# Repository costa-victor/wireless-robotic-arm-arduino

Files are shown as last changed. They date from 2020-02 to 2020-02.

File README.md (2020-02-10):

## Robotnik -> Equipe de robótica da UTFPR - Pato Branco
## Descrição do projeto:
Em resumo trata-se de um Braço robótico de 4 Eixos impresso em 3D controlado remotamente por um Controle de PS2 que consiste basicamente de 2 Módulos, conforme a imagem abaixo:

description

Os códigos comentados e todo o material necessário para criação e/ou continuação desde projeto estão contidos nesse repositório na pasta **Code**.

A seguir você encontrará a descrição do funcionamento, referências, demonstração e dicas para aprimorar o projeto atual.

### Module 1:
 A função do **Arduino** neste módulo é de receber e interpretar os dados ao pressionar/mover algum de seus botões/analógico do **Controle de PS2** e armazenar os dados em uma struct contendo o estado de cada botão e enviar para o **Module 2** via **Wireless RF** com o **NRF24L01**.
 
 **Hardware:**
 - 01x NRF24L01
 - 01x Arduino Uno
 - 01x Controle PS2 (qualquer)
 
 O **Controle PS2** utilizado foi um controle sem fio, contudo, as conexões permanecem as mesmas da imagem abaixo.
 
 
 
 Para mais informações sobre o **Module 1**, recomendo os materiais:
 * [Como funciona os pinos do Controle PS2]( http://microcontrolado.com/controle-playstation-no-pic-2/)
 * [Como funciona o NRF24L01]( https://lastminuteengineers.com/nrf24l01-arduino-wireless-communication/)
 * [Documentação da Lib para o NRF24L01]( https://maniacbug.github.io/RF24/classRF24.html#aeb9920e7a95699748b003c4a839b0814)

### Module 2:
 A função do **Arduino** neste módulo é de receber os dados enviados do **Module 1** e com isso gerar instruções para o jogador através do **Display LCD** e ao mesmo tempo enviar um sinal PWM aos **Servo-motores** para assim mover o **Braço Robótico de 4 eixos impresso em 3D**  como desejar, dentro dos movimentos que os **Servo-motores** permitem e são eles:
 
 - Rotaçao da **Base** em até 180º
 - Erguer/Abaixar o **Braço**
 - Esticar/Contrair o **Antebraço**
 - Fechar/Abrir **Garra** 

Todos os movimentos acima são exibidos no **Display LCD**.
 
 **Hardware:**
 - 01x NRF24L01
 - 01x Arduino Uno
 - 02x Servo-Motor SG90
 - 02x Servo-Motor MG995
 - 01x Fonte ATX (simples)

 Neste projeto foi necessário utilizar um **Servo-Motor MG995** para a movimentação do **Braço** e outro para movimentação do **Antebraço** por conta da necessidade de maior torque dos motores para funcionar, enquanto para a **Garra** e a **Base** a utilização do **Servo-Motor SG90** foi suficiente.
 
 Para alimentação do **Module 2**  foi utilizado uma **Fonte ATX**, pois é permitido executar os 4 movimentos simultaneamente e a utilização de um regulador linear como o **LM7805** não é suficiente para a alimentação de todo o **Module 2**, pois durante a execução de movimentos combinados a corrente necessária foi superior à **2,5 A** e portanto caso desejar uma solução mais elegante que a utilização de uma **Fonte ATX**, sugiro utilizar um **Conversor DC/DC (Step Down) LM2596** ou similar.
 
O projeto original, utilizado como base para montagem e adaptação em um braço robótico de 4 eixos que pode ser encontrado abaixo em **Montagem do Braço**, deste vários arquivos **STL** que compoêm o braço precisaram ser modificadas, pois o projeto original conta com uma **Bomba de Sucção**, que foi substituída por uma **Garra** e utilizada como referência o material abaixo **Garra adaptada**.

Todas as alterações nos arquivos **STL** foram realizadas utilizando o software **Autocad 2012 Student Version** e estão contidos neste repositório na pasta **3D Files**.

Todas as substituições de peças do projeto original podem ser comparadas acessando o arquivo **orçamento**.

 Para mais informações sobre o **Module 2**, recomendo os materiais:
 * [Documentação Lib Display LCD]( https://www.arduino.cc/en/Reference/LiquidCrystal)
 * [Montagem do Braço](https://www.youtube.com/watch?v=dlAjBVg1W2E&t=)
 * [Garra adaptada]( http://www.eezyrobots.it/eba_mk2.html#)

### Demonstração/Resultado:
Teste realizado antes de integrar com o montagem do braço impresso.

 demonstration1

Finalizado a montagem.

 final
 
 E deixando o melhor para o final, tem também um [vídeo](https://www.youtube.com/watch?v=mlnH6SM9yyg) demonstrando o funcionamento após o termino da montagem.

### Integrantes: Victor Alberti Costa e Murilo Santos Alves

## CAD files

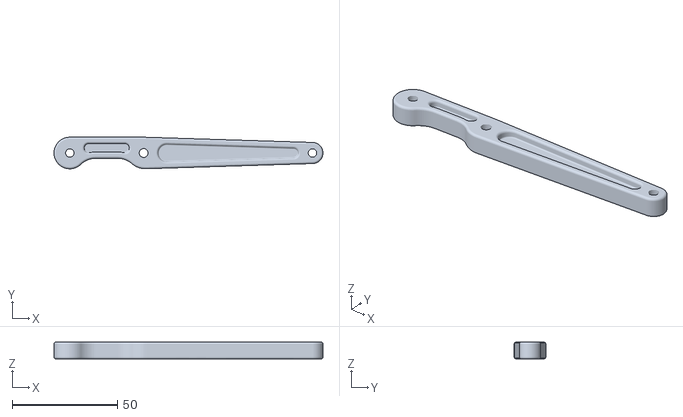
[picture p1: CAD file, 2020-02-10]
3D Files/Garra adaptada/EBA_01.00.005_horizontal_arm.STL
127.5 x 15.0 x 8.00

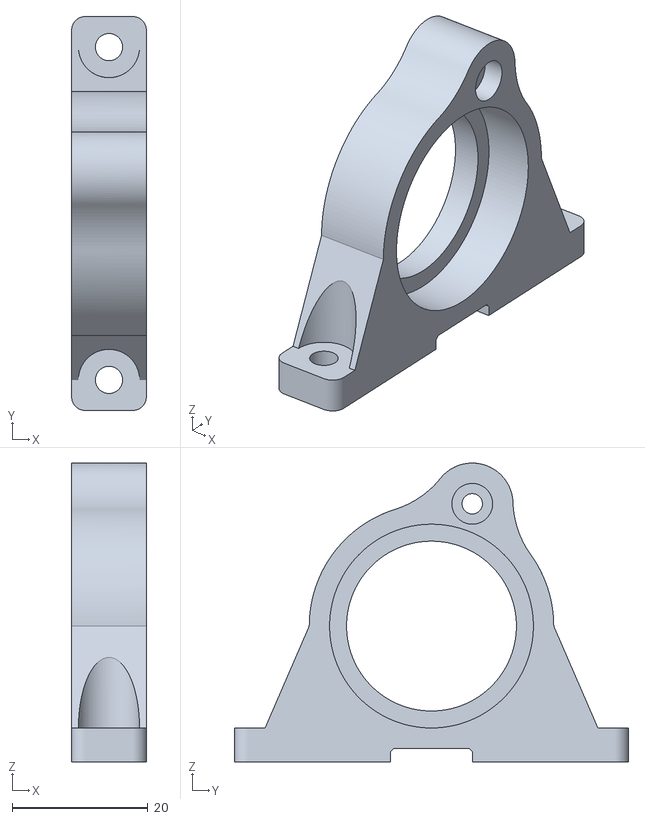
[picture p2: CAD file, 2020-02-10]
3D Files/stl/PART_9.stl
11.0 x 58.0 x 44.0

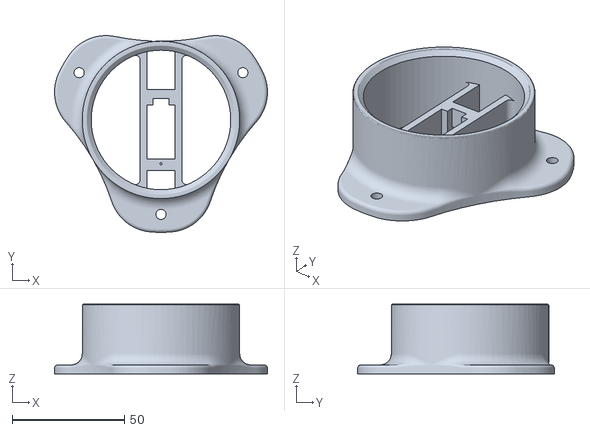
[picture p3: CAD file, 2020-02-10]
3D Files/Garra adaptada/EBA_01.00.010_basement.STL
94.7 x 87.5 x 31.0

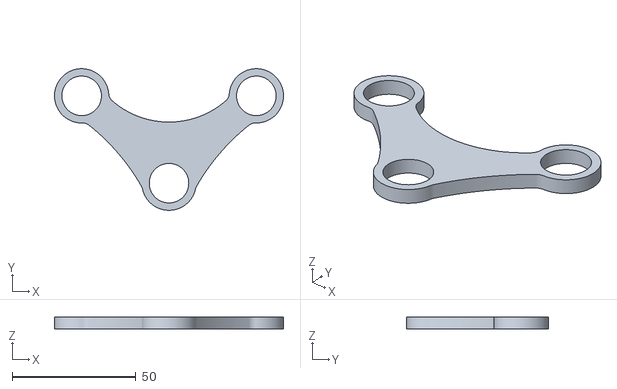
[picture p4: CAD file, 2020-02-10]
3D Files/stl/PART_17.stl
92.7 x 57.3 x 5.00

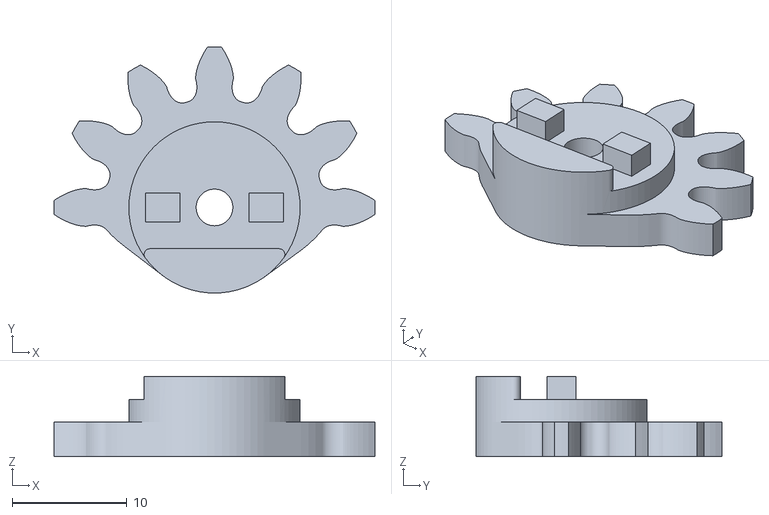
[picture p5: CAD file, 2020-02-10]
3D Files/Garra adaptada/EBA_01.00.016_R01_driven_gear.STL
28.0 x 21.5 x 7.00

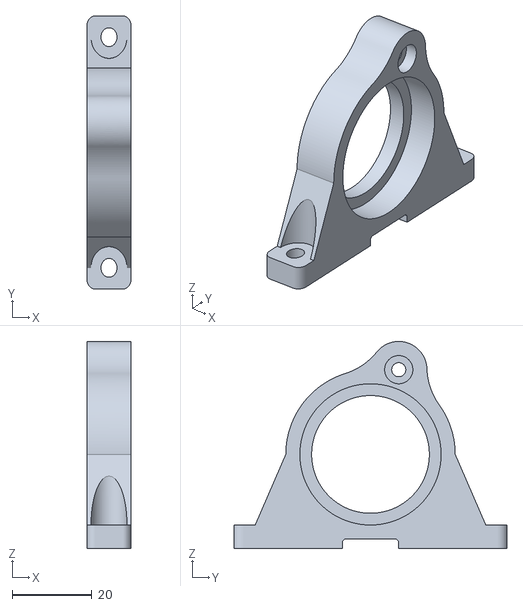
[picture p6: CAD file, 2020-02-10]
3D Files/stl/PART_9 - modificado.stl
11.0 x 68.4 x 51.9

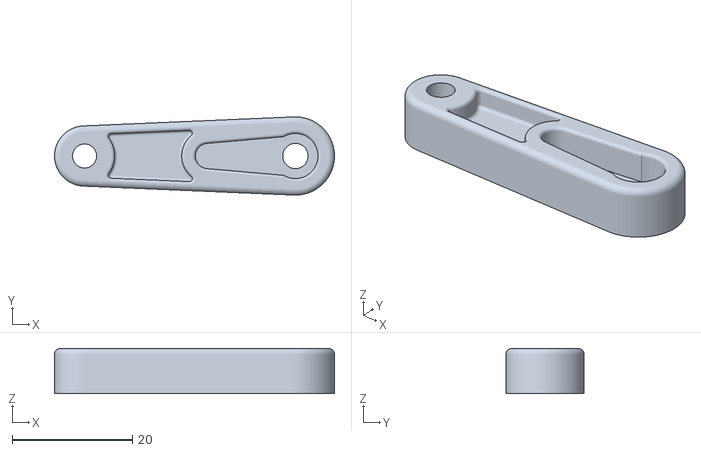
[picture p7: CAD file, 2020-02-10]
3D Files/Garra adaptada/EBA_01.00.002_vertical_drive_arm.STL
46.5 x 13.0 x 7.50

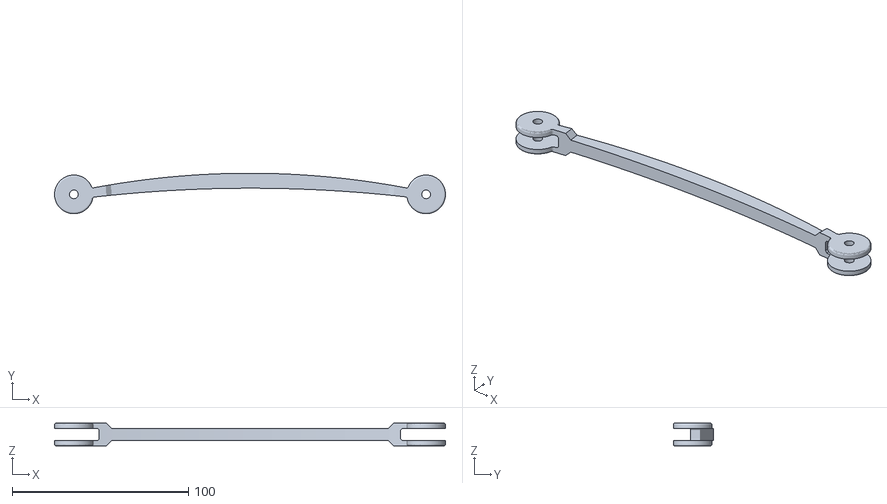
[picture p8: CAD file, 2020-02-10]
3D Files/stl/2x_PART_22.stl
222.0 x 23.0 x 13.0

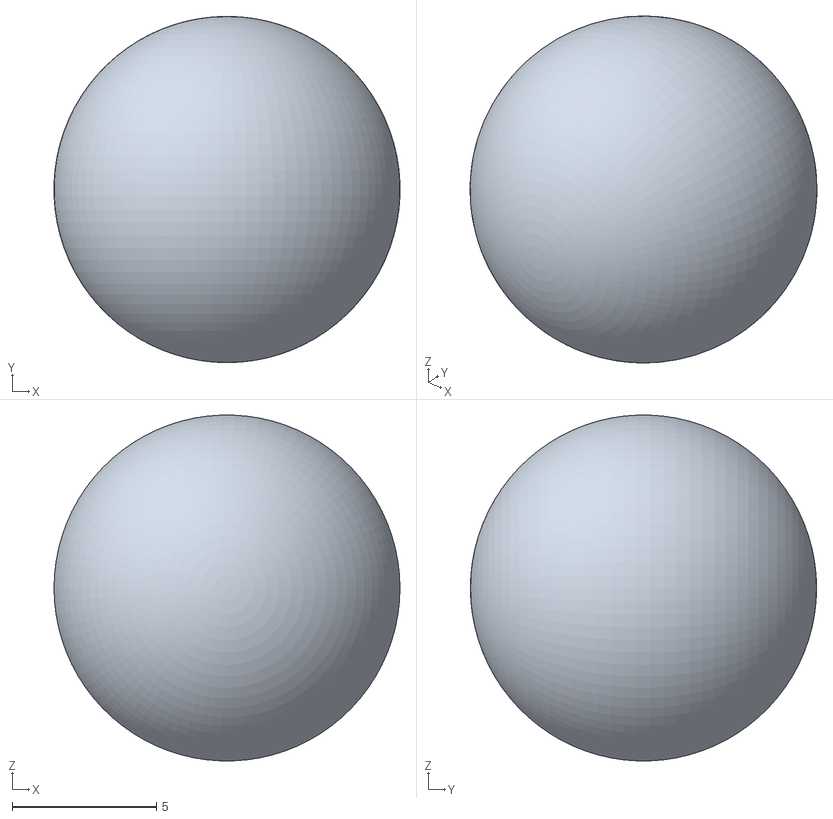
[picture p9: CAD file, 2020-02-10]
3D Files/Garra adaptada/EBA_01.00.019_ball.STL
12.0 x 12.0 x 12.0

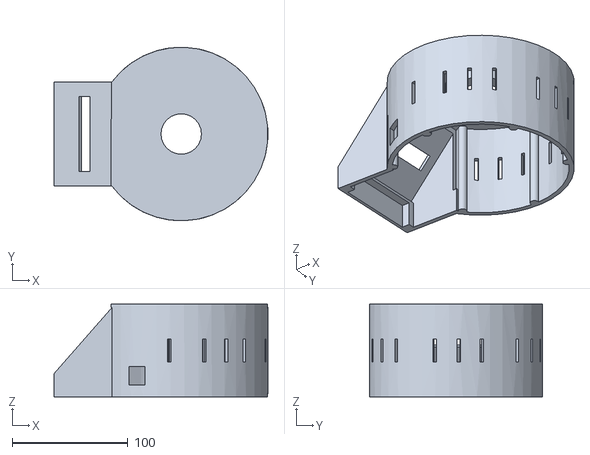
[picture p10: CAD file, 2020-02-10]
3D Files/stl/parte 1 - autocad - teste2.stl
185.0 x 149.9 x 80.0

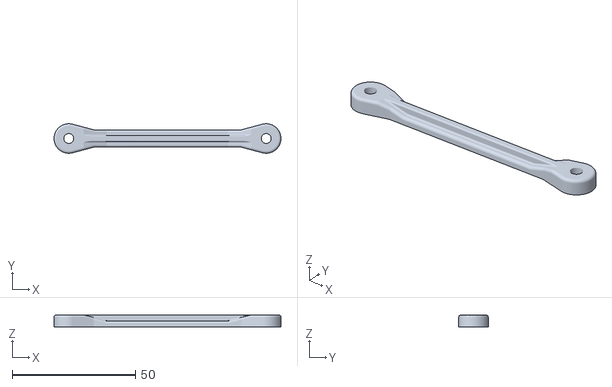
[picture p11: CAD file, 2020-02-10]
3D Files/Garra adaptada/EBA_01.00.003_link.STL
92.0 x 12.0 x 5.00

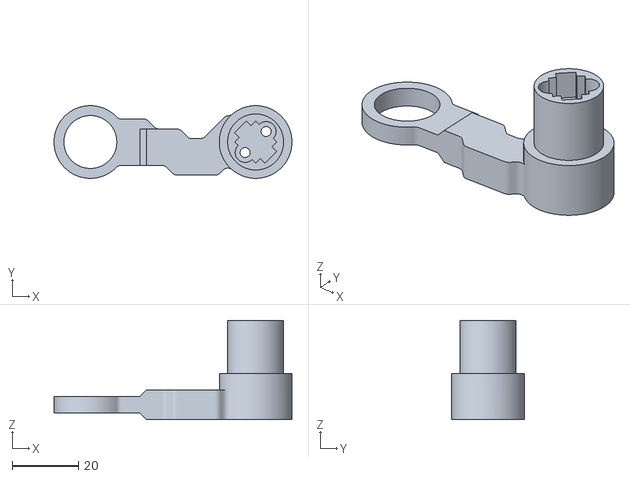
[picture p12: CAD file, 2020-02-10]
3D Files/stl/PART_10.stl
72.0 x 22.0 x 30.0

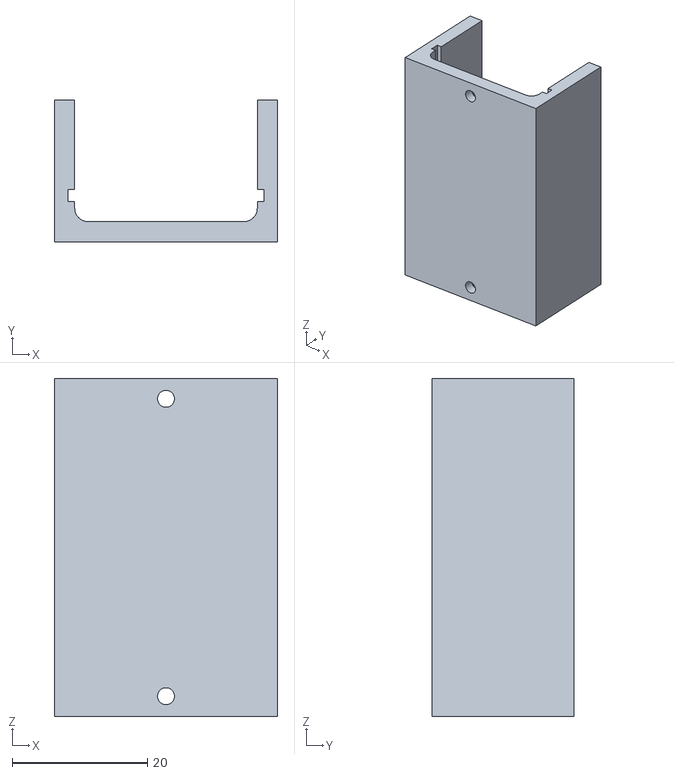
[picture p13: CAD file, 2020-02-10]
3D Files/Garra adaptada/EBA_01.00.018_maestro_holder.STL
33.0 x 21.0 x 50.0

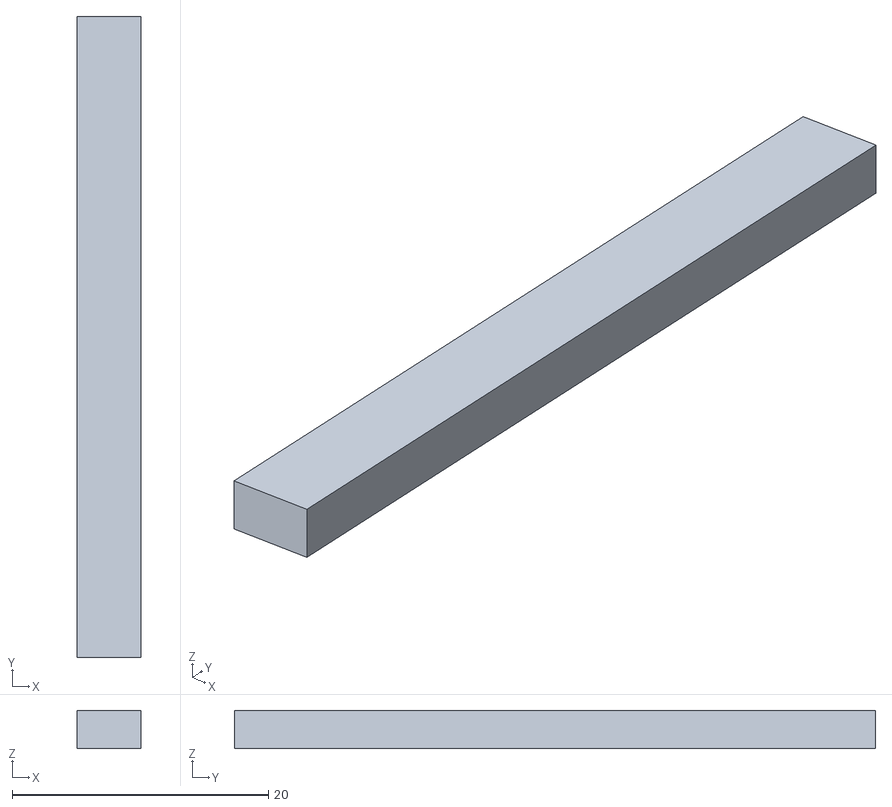
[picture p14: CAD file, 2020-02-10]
3D Files/stl/apoioAuxiliar.stl
5.00 x 50.0 x 3.00

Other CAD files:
3D Files/dwg/parte 23 - sketchup.dwg
3D Files/dwg/Peça 16 - autocad.dwg
3D Files/dwg/parte 9 - autocad.dwg
3D Files/Garra adaptada/EBA_01.00.013_R01_right_finger.STL
3D Files/Garra adaptada/EBA_01.00.001.STL
3D Files/Garra adaptada/EBA_01.00.004_forward_drive_arm.STL
3D Files/Garra adaptada/EBA_01.00.006_triangular_link.STL
3D Files/Garra adaptada/EBA_01.00.009_servo_plate.STL
3D Files/Garra adaptada/EBA_01.00.011_round_plate.STL
3D Files/Garra adaptada/EBA_01.00.012_R01_claw_support.STL
3D Files/Garra adaptada/EBA_01.00.014_R01_left_finger.STL
3D Files/Garra adaptada/EBA_01.00.015_drive_gear.STL
3D Files/Garra adaptada/EBA_01.00.017_R01_ramp.STL
3D Files/dwg/Peça 16 - autocad - pt1.dwg
3D Files/dwg/Peça 16 - autocad - pt2.dwg
3D Files/dwg/Peça 16 - autocad - pt3.dwg
3D Files/dwg/apoioAuxiliar.dwg
3D Files/dwg/apoioAuxiliarDaPt4.dwg
3D Files/dwg/apoioAuxiliarDoMotor.dwg
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

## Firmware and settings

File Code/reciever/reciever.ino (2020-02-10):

/* Projeto de oficina de integração --- Curso Engenharia de computação --- 7º Período
 * Autor: Victor Alberti Costa, Murilo Alves
 * Email: victorengcomp15@gmail.com
 * 
 * MÓDULO RECIEVER
 * 
 * Código referente ao módulo receptor de sinal proveniente do módulo RF do transmissor
 * e movimentação de 4 servomotores e um display LCD.
 * 
 * INSTRUÇÕES DE USO:
 *   Aberte START para começar
 *   Informe-se pelo display e divirta-se :)
 * 
 *    Movimentação BASE:
 *      ->  Seta para esquerda gera movimento no sentido Anti-horário
 *      ->  Seta para direita gera movimento no sentido Horário
 *      
 *    Movimentação BRAÇO:
 *      ->  Seta para cima gera movimento para frente
 *      ->  Seta para baixo gera movimento para trás
 *      
 *    Movimentação ANTEBRAÇO:
 *      ->  Analógico Direito pressionado para cima gera movimento para frente
 *      ->  Analógico Direito pressionado para baixo gera movimento para trás
 *      
 *    Movimentação GARRA:
 *      ->  Segurar R1 fecha a garra
 *      ->  Soltar R1 abre a garra
 */

#include <SPI.h>  
#include <RF24.h>
#include <Servo.h>
#include <LiquidCrystal.h>

LiquidCrystal lcd(7, 8, 5, 4, 3, 2); // lcd(rs, en, d4, d5, d6, d7) 
Servo base, braco, garra, antebraco;
RF24 myRadio (9, 10); // CE, CS

// variaveis utilizadas para controle do ang. dos servomotores
int posBase = 90;
int posBraco = 90;
int posAntebraco = 90;

// Estrutura dos dados que estão sendo enviados do transmissor - idem no transmissor
struct package
{
  int id=1;
  int LY;
  int LX;  
  int RY;
  int RX;
  int up;
  int down;
  int left;
  int right;
  int L1;
  int L2;
  int R1;
  int R2; 
  int start;  
  int x;
  int square;   // Consegue receber até aqui
  int triangle;
  int circle;
};

typedef struct package Package;
Package data;

// Definição do pipe de comunição do módulo RF
byte addresses[][6] = {"0"}; 

byte smiley[8] = {
  0b00000,
  0b00000,
  0b01010,
  0b00000,
  0b00000,
  0b10001,
  0b01110,
  0b00000
};


void setup() {
  // Incialização do display LCD
  lcd.begin(16, 2);
  lcd.createChar(1, smiley);
  lcd.clear();  
  
  // Mensagem inicial
  lcd.print("Pressione START");
  lcd.setCursor(0, 1);
  lcd.print("para comecar");

  // Inicialização dos servomotores
  base.attach(A5);
  braco.attach(A4);
  garra.attach(A0);
  antebraco.attach(A3);

  // Inicialização do monitor serial
  Serial.begin(57600);

  // Movimentação dos motores para testes
  delay(1000);
  base.write(90);
  braco.write(90);
  antebraco.write(90);
  garra.write(0);

  // Configuração do módulo RF
  // Documentação da biblioteca: https://maniacbug.github.io/RF24/classRF24.html#aeb9920e7a95699748b003c4a839b0814
  myRadio.begin(); 
  myRadio.setChannel(115);  // Canais de 0 - 127
  myRadio.setPALevel(RF24_PA_MAX);  // Power Level Amplifier - Máximo
  myRadio.openReadingPipe(1, addresses[0]);  // Numero identificador do pipe e seu endereço
  myRadio.setDataRate( RF24_250KBPS );  // Taxa de transmissão

  // Começa a ouvir o pipe
  myRadio.startListening(); 

  // Enquanto não ler o dado corresponde ao start, continua ouvindo
  do{
     if(myRadio.available()){
      while (myRadio.available()){
         myRadio.read( &data, sizeof(data) );
      }
    }  
  }while(!data.start);

  // Motivacional
  lcd.clear();
  lcd.setCursor(2, 0);
  lcd.print("Divirta-se ");
  lcd.write((byte)1);
}


void loop() {
  // Sempre que recebe um dado, lê e armazena na struct data
  if ( myRadio.available()) 
  {    
    while (myRadio.available())
    {
      myRadio.read( &data, sizeof(data) );
    }

  // Inicio da verificação dos dados para tomar ações

  // Caso seja pressionado botões que contradizem o movimento, informa o usuário
  if((data.left == 1 && data.right == 1) || (data.up == 1 && data.down == 1)){
        lcd.clear();      
        lcd.setCursor(4, 0);
        lcd.print("Movimento");      
        lcd.setCursor(5, 1);
        lcd.print("Invalido");
    }
    else{
          // Lógica para a base
          // Conectado: Pin A5

          // Se pressionado Seta Esquerda
          if(data.left == 1){
            if(data.right || data.up || data.down){
              lcd.clear();      
              lcd.setCursor(4, 0);
              lcd.print("Movimento");      
              lcd.setCursor(5, 1);
              lcd.print("Diagonal");               
            }
            else{
              lcd.clear();      
              lcd.setCursor(0, 0);
              lcd.print("Movendo BASE...");      
              lcd.setCursor(2, 1);
              lcd.print("Horario");
            }            
            // Para dar movimento mais fluido e restringir o movimento para não forçar a estrutura
            if(posBase >= 10){  
              posBase = posBase - 5; 
              base.write(posBase);
            }
            else{
              lcd.clear();      
              lcd.setCursor(0, 0);
              lcd.print("Cuidado");      
              lcd.setCursor(2, 1);
              lcd.print("Limite !!");              
            }
          }
          
          // Se pressionado Seta Direita
          else if(data.right == 1){ 
            if(data.left || data.up || data.down){
              lcd.clear();      
              lcd.setCursor(4, 0);
              lcd.print("Movimento");      
              lcd.setCursor(5, 1);
              lcd.print("Diagonal");               
            }
            else{             
              lcd.clear();      
              lcd.setCursor(0, 0);
              lcd.print("Movendo BASE...");      
              lcd.setCursor(2, 1);
              lcd.print("Anti-horario");
            }                    
            if(posBase <= 160){
              posBase = posBase + 5;
              base.write(posBase);
            }
            else{
              lcd.clear();      
              lcd.setCursor(0, 0);
              lcd.print("Cuidado");      
              lcd.setCursor(2, 1);
              lcd.print("Limite !!");              
            }
          }
      
          // Lógica para o braço
          // Conectado: Pin A4
          
          // Se pressionado a Seta Para cima
          if(data.up == 1){
            if(data.right || data.left || data.down){
              lcd.clear();      
              lcd.setCursor(4, 0);
              lcd.print("Movimento");      
              lcd.setCursor(5, 1);
              lcd.print("Diagonal");               
            }
            else{             
              lcd.clear();      
              lcd.setCursor(0, 0);
              lcd.print("Movendo BRACO...");      
              lcd.setCursor(2, 1);
              lcd.print("Frente");
            }
            
            // Para dar movimento mais fluido e restringir o movimento para não forçar a estrutura
            if(posBraco >= 10){
              posBraco = posBraco - 5;
              braco.write(posBraco);    
            }
            else{
              lcd.clear();      
              lcd.setCursor(0, 0);
              lcd.print("Cuidado");      
              lcd.setCursor(2, 1);
              lcd.print("Limite !!");              
            }
          }

          // Se pressionado a Seta Para Baixo
          else if(data.down){
            if(data.right || data.up || data.left){
              lcd.clear();      
              lcd.setCursor(4, 0);
              lcd.print("Movimento");      
              lcd.setCursor(5, 1);
              lcd.print("Diagonal");               
            }
            else{
            lcd.clear();      
            lcd.setCursor(0, 0);
            lcd.print("Movendo BRACO...");      
            lcd.setCursor(2, 1);
            lcd.print("Atras");
            }

            // Reduzindo velocidade do braço
            if(posBraco <= 170){
              posBraco = posBraco + 5;
              braco.write(posBraco);
                
            }
            else{
              lcd.clear();      
              lcd.setCursor(0, 0);
              lcd.print("Cuidado");      
              lcd.setCursor(2, 1);
              lcd.print("Limite !!");              
            }            
          }

          // Como os motores utilizados são fracos eles não conseguem manter o braço imóvel, então quando
          // nada é pressionado o motor tenta manter o braço imóvel
          else if(!data.up && !data.down){
            posBraco = 90;
            braco.write(posBraco);
          }

         
          // Lógica para o Antebraço
          // Conectado: Pin A3
          
          // Se pressionado o analógico direito   
          if(data.RY < 127){
            lcd.clear();      
            lcd.setCursor(0, 0);
            lcd.print("Mov. ANTEBRACO");      
            lcd.setCursor(2, 1);
            lcd.print("Para cima");

            // Valores do PWM ajustados empiricamente
            // Parte onde necessita de maior torque dos motores, portanto o movimento mais suave
            // não dava bons resultados
            antebraco.write(0);
          }
          else if(data.RY > 127){
            lcd.clear();      
            lcd.setCursor(0, 0);
            lcd.print("Mov. ANTEBRACO");      
            lcd.setCursor(2, 1);
            lcd.print("Para baixo");

            antebraco.write(180);
          }
          // Como os motores utilizados são fracos eles não conseguem manter o braço imóvel, então quando
          // nada é pressionado o motor tenta manter o braço imóvel
          else if(data.RY == 127){
            antebraco.write(90);
          }

      
          // Lógica para a garra  -- microservo
          // Conectado: Pin A0
          
          // Se R2 estiver pressionado
          if(data.R2){
            lcd.setCursor(0, 0);
            lcd.clear();
            lcd.print("Ativando GARRA");

            garra.write(120);
          }
          else{
            garra.write(0);      
          }

          // Se nada estiver pressionado
          if(!data.left && !data.right && !data.up & !data.down && !data.R2 && data.RY == 127)
            lcd.clear();
      }            
  }

  // Para verificação no monitor serial
  Serial.print("\nPackage Receptor: ");
  Serial.print(data.id);
  Serial.print("\n");
  Serial.println(data.LX, DEC);
  Serial.print(",");
  Serial.println(data.LY, DEC);
  Serial.print(",");
  Serial.println(data.RX, DEC);
  Serial.print(",");
  Serial.println(data.RY, DEC);
  Serial.print("X: ");
  Serial.print(data.x);
  Serial.println("");
  
  Serial.print("Square: ");
  Serial.print(data.square);
  Serial.println("");
  
  Serial.print("Triangle: ");
  Serial.print(data.triangle);
  Serial.println("");
  
  Serial.print("Circle: ");
  Serial.print(data.circle);
  Serial.println("");
  
  Serial.print("Start: ");
  Serial.print(data.start);
  Serial.println("");

  Serial.print("up: ");
  Serial.print(data.up);
  Serial.println("");

  Serial.print("down: ");
  Serial.print(data.down);
  Serial.println("");

  Serial.print("left: ");
  Serial.print(data.left);
  Serial.println("");

  Serial.print("right: ");
  Serial.print(data.right);
  Serial.println("");


  Serial.print("L1: ");
  Serial.print(data.L1);
  Serial.println("");

  Serial.print("R1: ");
  Serial.print(data.R1);
  Serial.println("");

  Serial.print("L2: ");
  Serial.print(data.L2);
  Serial.println("");

  
  Serial.print("R2: ");
  Serial.print(data.R2);
  Serial.println("");
 
  data.id = data.id + 1;

}

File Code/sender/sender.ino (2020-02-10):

#include <PS2X_lib.h>
#include <SPI.h>
#include <RF24.h>
#include <printf.h>

RF24 myRadio (9, 10); // CE, CS
PS2X ps2x; // Criação de uma instancia de controle PS2

int error = 0;
byte type = 0;
byte vibrate = 0;

byte addresses[][6] = {"0"};

struct package
{
  int id=1;
  int LY;
  int LX;  
  int RY;
  int RX;
  int up;
  int down;
  int left;
  int right;
    int L1;
  int L2;
  int R1;
  int R2;
    int start;  
  int x;
  int square;   // Envia até aqui
  int triangle;
  int circle;


};


typedef struct package Package;
Package data;

void setup() { 
  // Address: 0
  // Channel: 115
  // Data Rate: 250 Kbit
  
  // Inicialização da comunicação serial
  Serial.begin(57600);
  delay(1000);
  
  // Configuraçao do modulo RF
  myRadio.begin();  
  myRadio.setChannel(115);  // Modulo suporta 128 canais diferentes, definimos o canal do pipe que queremos usar para a comunicação
  myRadio.setPALevel(RF24_PA_MAX);    // seta o valor maximo de poder para o alcance do modulo
  myRadio.setDataRate( RF24_250KBPS ) ;   //  data rate da transmissão -- menor datarate possível pra atender melhor o longo alcance
  myRadio.openWritingPipe( addresses[0]); // abrindo o pipe para comunicaação

   // Configuração do controle PS2
   // GamePad(clock, command, attention, data, Pressures?, Rumble?)
   error = ps2x.config_gamepad(8,6,5,7, false, false);  

    // Confirmação de sucesso ou falha
   if(error == 0){
     Serial.println("Found Controller, configured successful");
     Serial.println("Try out all the buttons, X will vibrate the controller, faster as you press harder;");
     Serial.println("holding L1 or R1 will print out the analog stick values.");
     Serial.println("Go to www.billporter.info for updates and to report bugs.");
   }
   else if(error == 1)
     Serial.println("No controller found, check wiring, see readme.txt to enable debug. visit www.billporter.info for troubleshooting tips");
   else if(error == 2)
     Serial.println("Controller found but not accepting commands. see readme.txt to enable debug. Visit www.billporter.info for troubleshooting tips");
   else if(error == 3)
     Serial.println("Controller refusing to enter Pressures mode, may not support it. ");
   
   // Tipo de controle suportado
   type = ps2x.readType(); 
   switch(type) {
       case 0:
        Serial.println("Unknown Controller type");
       break;
       case 1:
        Serial.println("DualShock Controller Found");
       break;
       case 2:
         Serial.println("GuitarHero Controller Found");
       break;
   }
   delay(1000);
}

void loop() {
  // Lê as informações do controle o controle  
  ps2x.read_gamepad(false, vibrate);

  // Armazenando os dados de cada botão lido em variaveis da estrutura para ser enviados
  data.LX = ps2x.Analog(PSS_LX);
  data.LY = ps2x.Analog(PSS_LY);
  data.RX = ps2x.Analog(PSS_RX);
  data.RY = ps2x.Analog(PSS_RY);

  data.up = ps2x.Button(PSB_PAD_UP);
  data.down = ps2x.Button(PSB_PAD_DOWN);
  data.left = ps2x.Button(PSB_PAD_LEFT);
  data.right = ps2x.Button(PSB_PAD_RIGHT);

  data.x = ps2x.Button(PSB_CROSS);
  data.square = ps2x.Button(PSB_SQUARE);
  data.triangle = ps2x.Button(PSB_TRIANGLE);
  data.circle = ps2x.Button(PSB_CIRCLE);
  data.start = ps2x.Button(PSB_START);
  data.L1 = ps2x.Button(PSB_L1);
  data.L2 = ps2x.Button(PSB_L2);
  data.R1 = ps2x.Button(PSB_R1);
  data.R2 = ps2x.Button(PSB_R2);
  
  // Trasmissao dos dados
  myRadio.write(&data, sizeof(data)); 
  
  // Verificação no monitor serial
  Serial.print("\nPackage Transmitter: ");
  Serial.print(data.id);
  Serial.print("\n");
  Serial.println(data.LX, DEC);
  Serial.print(",");
  Serial.println(data.LY, DEC);
  Serial.print(",");
  Serial.println(data.RX, DEC);
  Serial.print(",");
  Serial.println(data.RY, DEC);
  Serial.print("X: ");
  Serial.print(data.x);
  Serial.println("");
  
  Serial.print("Square: ");
  Serial.print(data.square);
  Serial.println("");
  
  Serial.print("Triangle: ");
  Serial.print(data.triangle);
  Serial.println("");
  
  Serial.print("Circle: ");
  Serial.print(data.circle);
  Serial.println("");
  
  Serial.print("Start: ");
  Serial.print(data.start);
  Serial.println("");

  Serial.print("up: ");
  Serial.print(data.up);
  Serial.println("");

    Serial.print("down: ");
  Serial.print(data.down);
  Serial.println("");

    Serial.print("left: ");
  Serial.print(data.left);
  Serial.println("");

    Serial.print("right: ");
  Serial.print(data.right);
  Serial.println("");

  Serial.print("L1: ");
  Serial.print(data.L1);
  Serial.println("");

  Serial.print("R1: ");
  Serial.print(data.R1);
  Serial.println("");

  Serial.print("L2: ");
  Serial.print(data.L2);
  Serial.println("");

  
  Serial.print("R2: ");
  Serial.print(data.R2);
  Serial.println("");
  
  data.id = data.id + 1;
  
  delay(50);
}
